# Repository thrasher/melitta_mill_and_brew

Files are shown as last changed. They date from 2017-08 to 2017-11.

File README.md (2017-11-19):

## Melitta Mill and Brew Coffee Maker Parts

See details on Thingiverse:
https://www.thingiverse.com/thing:1547304

### Summary

This is a replacement grinder lock for the Melita Mill and Brew coffee maker.  I've had this coffee maker since 2003 (over 14 years), and really like the flavor of coffee it makes.  Everyone that tries it says "wow, that's good coffee".  However, the built-in grinder body has two locking levers that broke with years of use.  You can get spare parts on ebay, but why not print them?!

The basket has two of these locks, so print one, and make sure it works for you before printing a second.  To remove the old locks, use a flathead screwdriver to pry the old lock out, being careful not to break the axel nubs that let the part pivot to lock in place.

**Update 11/17/2017**
The first design could warp if printed with PLA, from the heat of brewing the coffee.  I've improved the design, so that the heat from brewing doesn't deform the parts.  It's now a two part, and should be printed at 100% infill.  The plug fits into the paddle, after being installed in the grinder basket, to keep it from warping.

**Instructions**
1. Print the paddle at 100% infill
1. Print the plug at 100% infill
1. Clean up the hole to fit the basket's pivots with a drill bit
1. Mount the paddle in the basket, with the spring in place
1. Push the plug into the paddle, to lock the two parts in
1. Brew coffee

Download from Thingiverse, or find the files here:
https://github.com/thrasher/melitta_mill_and_brew

### Print Settings

My prints were done with all of the default MakerBot Mini settings, except infill which must be 100%

### Post Printing

I used a 1/8 drill bit to expand the holes on either side of the part, to match the axel nubs on the grinder body.  On the MakerBot Mini, since it prints rafts, I used a metal file to cut down the outside surface raft and make it smooth.  The hole size for the spring is a little loose, but it works fine.  It required too much trial/error to get it exact, so I avoided that by making it slightly large.

Gently wedge the part on the axel nubs on the grinder body, and don't forget the spring!  Work it back and forth a few times if it's a tight fit.  Remove and use a file to cut down the shape further if it's binding.  It shouldn't bind at all.

### How I Designed This

I just copied the existing broken part with a caliper, sketching it into Sketchup, and taking liberties where needed.  After some use with the first version, it deformed from the heat of brewing, and popped off.  The newer design has been trouble free.

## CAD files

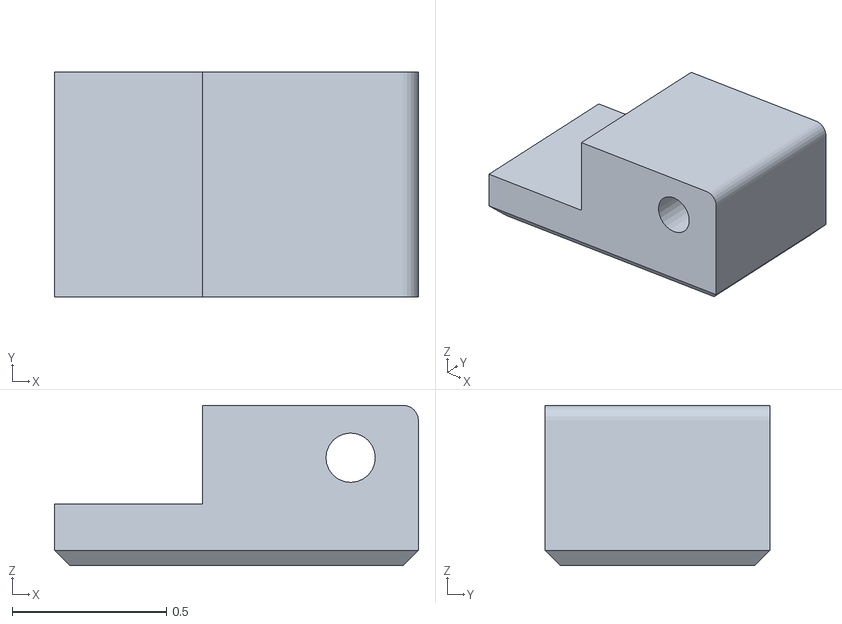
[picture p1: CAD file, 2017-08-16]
plug.stl
1.18 x 0.73 x 0.52

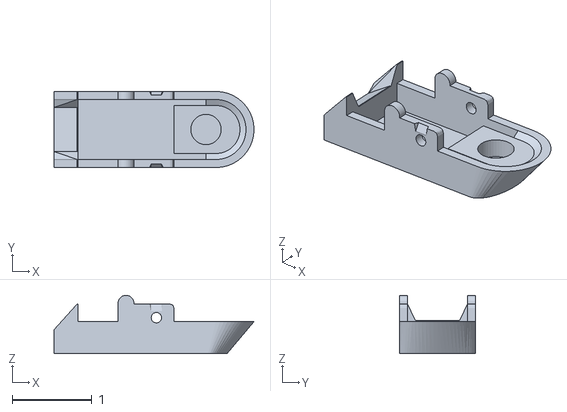
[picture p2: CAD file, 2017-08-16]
paddle.stl
2.50 x 0.95 x 0.73

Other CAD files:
paddle.skp

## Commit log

2016-12-28 paddle for grinder basket
    [paddle.skp, paddle.stl]
2017-08-16 Changed geometry of peg ramps so wall is thicker, reducing deformation due to heat from the coffee brewing process. Changed to 100% infill, again to reduce deformation due to heat from coffee brewing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
    [paddle.skp, paddle.stl, plug.stl]
